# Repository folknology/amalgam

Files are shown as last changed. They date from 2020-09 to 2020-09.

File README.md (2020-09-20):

# Amalgam
Amalgam an OpenSource hardware fusion of FPGA and Cortex M7 Microcontroller in a [BlackEdge](https://github.com/folknology/BlackEdge) compatible layout, a project of the myStorm communtiy.

Current status is hardware design, you can see the developments we are making on my regular streams :
*  [Live Stream, 8pm BST](https://www.twitch.tv/folknology)
* [Historic streams](https://www.youtube.com/watch?v=79OoLG_Dxk0&list=PLXS9jyX9czzodpJNL-szsMfl0rOrZk4B7)
Or at the join us at the [myStorm community forum](https://forum.mystorm.uk)

We will be using an Alloy fusion framework on top of [nMigen](https://github.com/m-labs/nmigen) and [Circuit Python](https://github.com/adafruit/circuitpython) alonmg with verilog using [Yosys](https://github.com/YosysHQ/yosys)

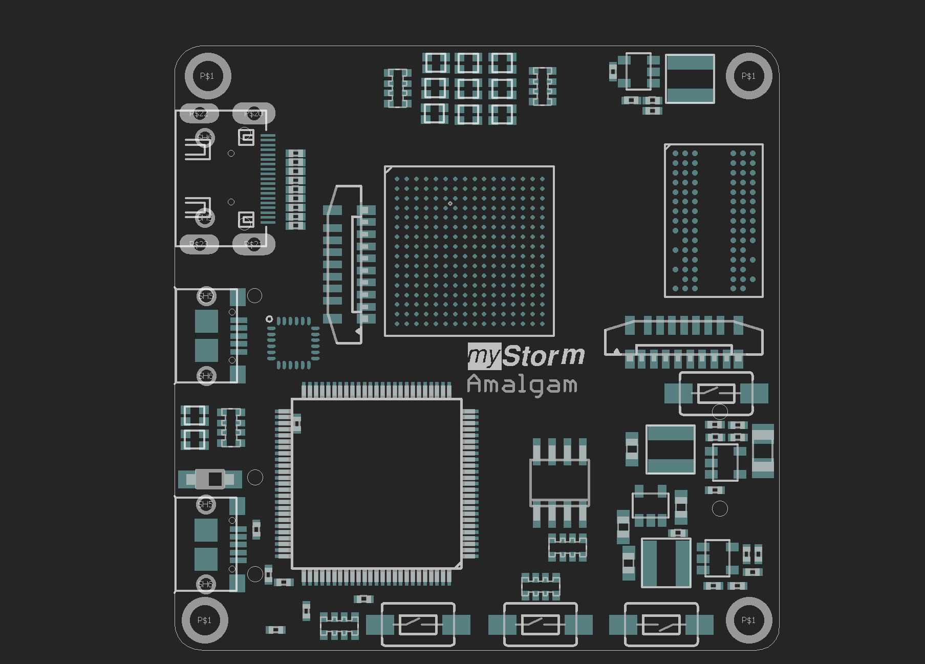
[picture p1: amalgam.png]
Amalgam


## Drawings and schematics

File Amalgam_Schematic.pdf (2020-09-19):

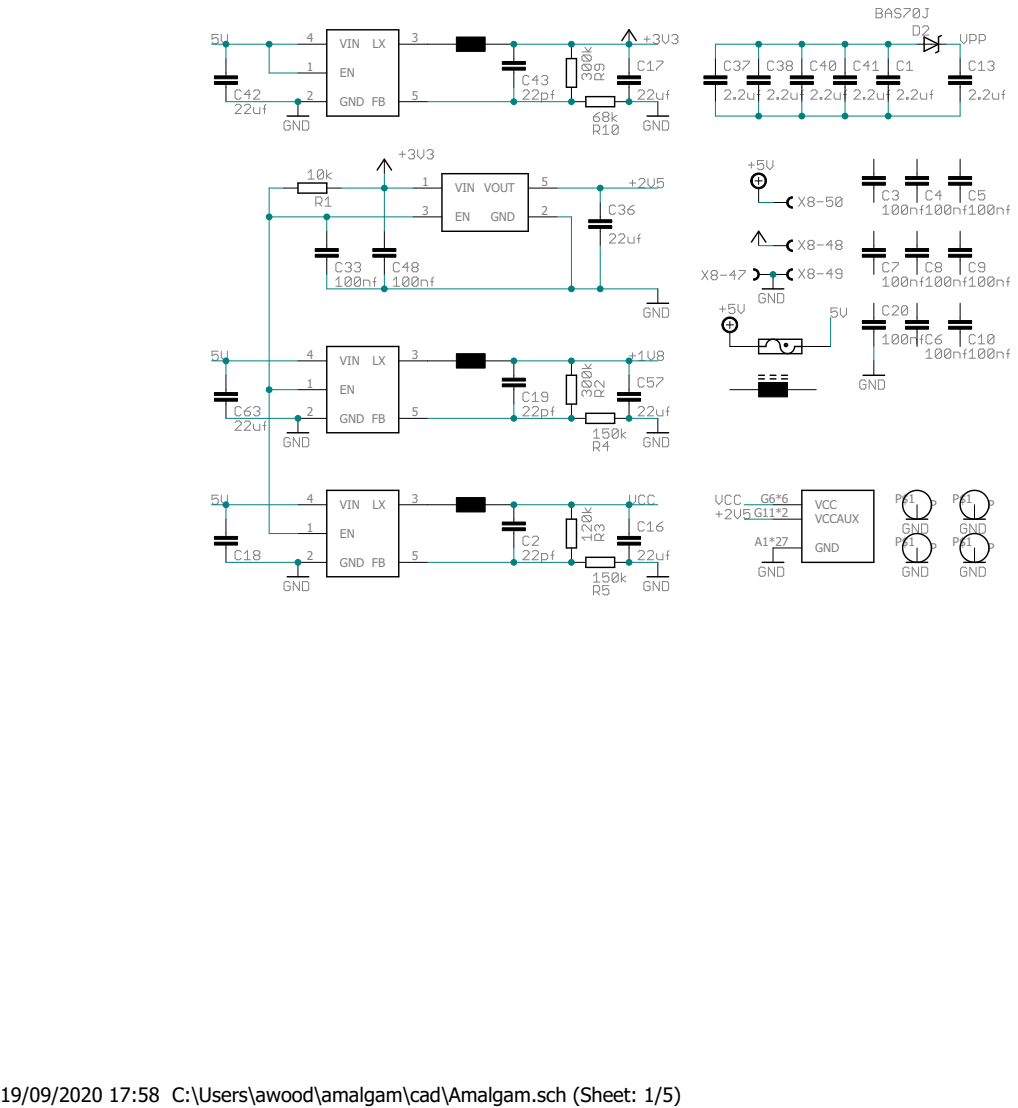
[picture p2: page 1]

19/09/2020 17:58 C:\Users\awood\amalgam\cad\Amalgam.sch (Sheet: 1/5)

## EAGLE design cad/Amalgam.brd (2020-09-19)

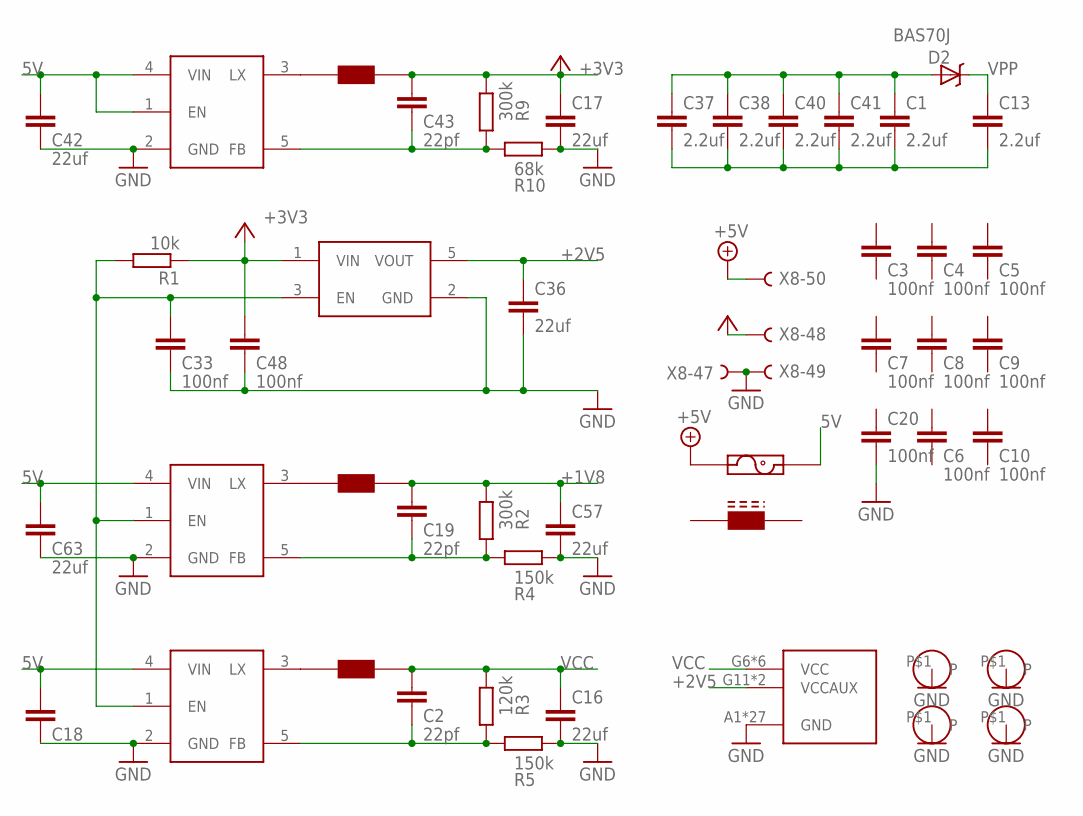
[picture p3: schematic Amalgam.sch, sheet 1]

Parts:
C1, C13, C37, C38, C40, C41: 2.2uf; C0603
C2, C19, C43: 22pf; C0402
C3, C4, C5, C6, C7, C8, C9, C10, C20, C33, C48: 100nf; C0402
C16, C17, C36, C57: 22uf; C0603
C18, C42, C63: 22uf; C0402
D2: BAS70J; SOD-323
IC7: NCP114; TSOP-5/SOT23-5
R1: 10k; R0402
R2, R9: 300k; R0402
R3: 120k; R0402
R4, R5: 150k; R0402
R10: 68k; R0402
U$1: PTC-1206; 1206
U$7, U$15, U$16, U$17: HOLE-2.5MM; 2.5MM-HOLE
U$12, U$13, U$20: AP3429/A; TSOP-5/SOT23-5
U$14: LFE5-XX256CABGA256; CABGA256
U$18, U$19, U$23: NRS4018; NRC4018
U$21: FERRITE_BEAD1206; 1206
X8: 1296-T50; 1296-50

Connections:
5V: C18.2, C42.2, C63.2, U$1.2, U$12.4 (VIN), U$13.4 (VIN), U$20.1 (EN), U$20.4 (VIN); also elsewhere on the board
+1V8: C19.2, C57.1, R2.2, U$19.P$2; also elsewhere on the board
+2V5: C36.1, IC7.5 (VOUT), U$14.G11 (VCCAUX), U$14.L7 (VCCAUX)
+3V3: C17.1, C43.2, C48.2, IC7.1 (VIN), R1.1, R9.2, U$23.P$2, X8.48; also elsewhere on the board
+5V: U$1.1, X8.50; also elsewhere on the board
GND: C16.2, C17.2, C18.1, C20.2, C33.1, C36.2, C42.1, C48.1, C57.2, C63.1, IC7.2 (GND), R4.2, R5.2, R10.2, U$7.P$1, U$12.2 (GND), U$13.2 (GND), U$14.A1 (GND), U$14.A16 (GND), U$14.D2 (GND), U$14.D15 (GND), U$14.F8 (GND), U$14.F9 (GND), U$14.G8 (GND), U$14.G10 (GND), U$14.H1 (GND), U$14.H8 (GND), U$14.H9 (GND), U$14.H10 (GND), U$14.H16 (GND), U$14.J8 (GND), U$14.J9 (GND), U$14.J10 (GND), U$14.K6 (GND), U$14.K7 (GND), U$14.K8 (GND), U$14.K9 (GND), U$14.K10 (GND), U$14.N2 (GND), U$14.N15 (GND), U$14.T1 (GND), U$14.T5 (GND), U$14.T12 (GND), U$14.T16 (GND), U$15.P$1, U$16.P$1, U$17.P$1, U$20.2 (GND), X8.47, X8.49; also elsewhere on the board
unnamed: C33.2, IC7.3 (EN), R1.2, U$12.1 (EN), U$13.1 (EN)
unnamed: C19.1, R2.1, R4.1, U$12.5 (FB)
unnamed: U$13.3 (LX), U$18.P$1
unnamed: U$12.3 (LX), U$19.P$1
unnamed: C2.1, R3.1, R5.1, U$13.5 (FB)
unnamed: C43.1, R9.1, R10.1, U$20.5 (FB)
unnamed: U$20.3 (LX), U$23.P$1
unnamed: C1.2, C13.2, C37.2, C38.2, C40.2, C41.2
unnamed: C1.1, C37.1, C38.1, C40.1, C41.1, D2.A
VCC: C2.2, C16.1, R3.2, U$14.G6 (VCC), U$14.G7 (VCC), U$14.G9 (VCC), U$14.L8 (VCC), U$14.L9 (VCC), U$14.L10 (VCC), U$18.P$2
VPP: C13.1, D2.C

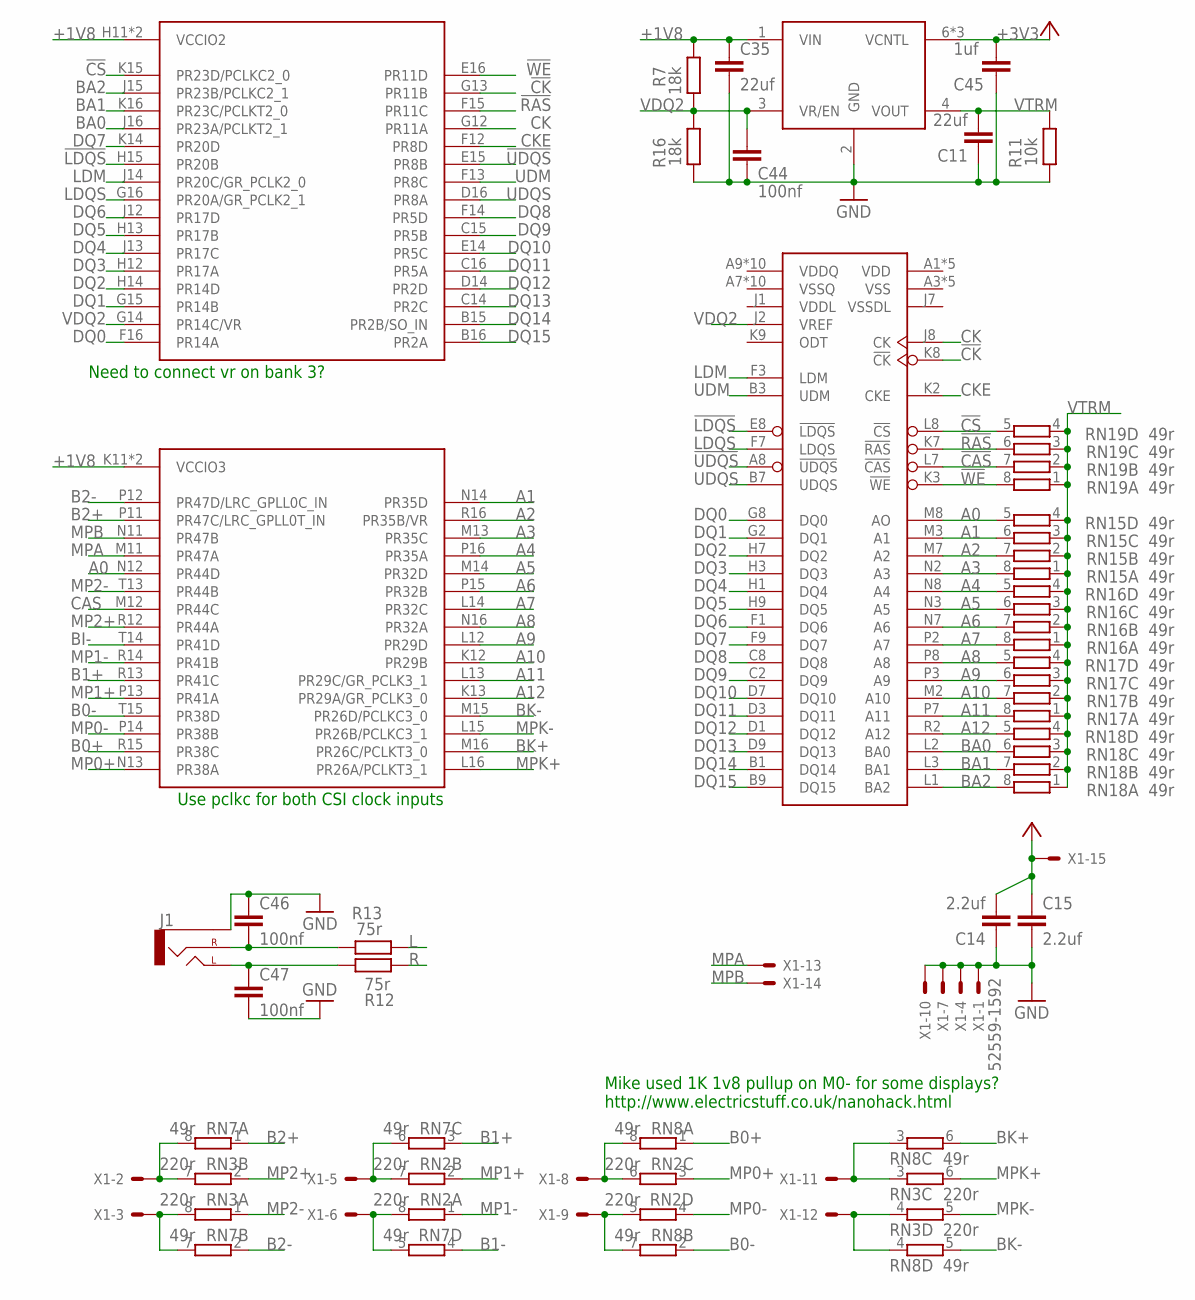
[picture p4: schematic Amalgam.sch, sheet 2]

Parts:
C11, C35: 22uf; C0603
C14, C15: 2.2uf; C0603
C44: 100nf; C0402
C45: 1uf; C0402
C46, C47: 100nf; C0603
J1: AUDIO_JACK_2.5MM_2.5MM_SMD; STEREOJACK2.5MM
R7, R16: 18k; R0402
R11: 10k; R0402
R12, R13: 75r; R0402
RN2, RN3: 220r; EXB38V
RN7, RN8, RN15, RN16, RN17, RN18, RN19: 49r; EXB38V
U$4: DDR2; WBGA-84
U$14: LFE5-XX256CABGA256; CABGA256
U$22: AP2303; SOIC-8-NARROW
X1: 52559-1592

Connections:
!CAS: RN19.7 (2), U$4.L7 (!CAS)
!CK: U$4.K8 (!CK), U$14.G13 (PR11B)
!CS: RN19.5 (2), U$4.L8 (!CS), U$14.K15 (PR23D/PCLKC2_0)
!LDQS: U$4.E8 (!LDQS), U$14.H15 (PR20B)
!RAS: RN19.6 (2), U$4.K7 (!RAS), U$14.F15 (PR11C)
!UDQS: U$4.A8 (!UDQS), U$14.E15 (PR8B)
!WE: RN19.8 (2), U$4.K3 (!WE), U$14.E16 (PR11D)
+1V8: C35.1, R7.1, U$14.H11 (VCCIO2), U$14.J11 (VCCIO2), U$14.K11 (VCCIO3), U$14.L11 (VCCIO3), U$22.1 (VIN); also elsewhere on the board
+3V3: C14.2, C15.1, C45.2, U$22.6 (VCNTL), U$22.7 (VCNTL), U$22.8 (VCNTL), X1.15; also elsewhere on the board
A0: RN15.5 (2), U$4.M8 (AO), U$14.N12 (PR44D)
A1: RN15.6 (2), U$4.M3 (A1), U$14.N14 (PR35D)
A2: RN15.7 (2), U$4.M7 (A2), U$14.R16 (PR35B/VR)
A3: RN15.8 (2), U$4.N2 (A3), U$14.M13 (PR35C)
A4: RN16.5 (2), U$4.N8 (A4), U$14.P16 (PR35A)
A5: RN16.6 (2), U$4.N3 (A5), U$14.M14 (PR32D)
A6: RN16.7 (2), U$4.N7 (A6), U$14.P15 (PR32B)
A7: RN16.8 (2), U$4.P2 (A7), U$14.L14 (PR32C)
A8: RN17.5 (2), U$4.P8 (A8), U$14.N16 (PR32A)
A9: RN17.6 (2), U$4.P3 (A9), U$14.L12 (PR29D)
A10: RN17.7 (2), U$4.M2 (A10), U$14.K12 (PR29B)
A11: RN17.8 (2), U$4.P7 (A11), U$14.L13 (PR29C/GR_PCLK3_1)
A12: RN18.5 (2), U$4.R2 (A12), U$14.K13 (PR29A/GR_PCLK3_0)
B0+: RN8.1, U$14.R15 (PR38C)
B0-: RN8.2 (1), U$14.T15 (PR38D)
B1+: RN7.3 (1), U$14.R13 (PR41C)
B1-: RN7.4 (1)
B2+: RN7.1, U$14.P11 (PR47C/LRC_GPLL0T_IN)
B2-: RN7.2 (1), U$14.P12 (PR47D/LRC_GPLL0C_IN)
BA0: RN18.6 (2), U$4.L2 (BA0), U$14.J16 (PR23A/PCLKT2_1)
BA1: RN18.7 (2), U$4.L3 (BA1), U$14.K16 (PR23C/PCLKT2_0)
BA2: RN18.8 (2), U$4.L1 (BA2), U$14.J15 (PR23B/PCLKC2_1)
BI-: U$14.T14 (PR41D)
BK+: RN8.6 (2), U$14.M16 (PR26C/PCLKT3_0)
BK-: RN8.5 (2), U$14.M15 (PR26D/PCLKC3_0)
CAS: U$14.M12 (PR44C)
CK: U$4.J8 (CK), U$14.G12 (PR11A)
CKE: U$4.K2 (CKE), U$14.F12 (PR8D)
DQ0: U$4.G8 (DQ0), U$14.F16 (PR14A)
DQ1: U$4.G2 (DQ1), U$14.G15 (PR14B)
DQ2: U$4.H7 (DQ2), U$14.H14 (PR14D)
DQ3: U$4.H3 (DQ3), U$14.H12 (PR17A)
DQ4: U$4.H1 (DQ4), U$14.J13 (PR17C)
DQ5: U$4.H9 (DQ5), U$14.H13 (PR17B)
DQ6: U$4.F1 (DQ6), U$14.J12 (PR17D)
DQ7: U$4.F9 (DQ7), U$14.K14 (PR20D)
DQ8: U$4.C8 (DQ8), U$14.F14 (PR5D)
DQ9: U$4.C2 (DQ9), U$14.C15 (PR5B)
DQ10: U$4.D7 (DQ10), U$14.E14 (PR5C)
DQ11: U$4.D3 (DQ11), U$14.C16 (PR5A)
DQ12: U$4.D1 (DQ12), U$14.D14 (PR2D)
DQ13: U$4.D9 (DQ13), U$14.C14 (PR2C)
DQ14: U$4.B1 (DQ14), U$14.B15 (PR2B/SO_IN)
DQ15: U$4.B9 (DQ15), U$14.B16 (PR2A)
GND: C11.1, C14.1, C15.2, C35.2, C44.1, C45.1, C46.1, C47.2, J1.5 (SLEEVE), R11.2, R16.2, U$22.2 (GND), X1.1, X1.4, X1.7, X1.10; also elsewhere on the board
L: R13.1; also elsewhere on the board
LDM: U$4.F3 (LDM), U$14.J14 (PR20C/GR_PCLK2_0)
LDQS: U$4.F7 (LDQS), U$14.G16 (PR20A/GR_PCLK2_1)
MP0+: RN2.3 (1), U$14.N13 (PR38A)
MP0-: RN2.4 (1), U$14.P14 (PR38B)
MP1+: RN2.2 (1), U$14.P13 (PR41A)
MP1-: RN2.1, U$14.R14 (PR41B)
MP2+: RN3.2 (1), U$14.R12 (PR44A)
MP2-: RN3.1, U$14.T13 (PR44B)
MPA: U$14.M11 (PR47A), X1.13
MPB: U$14.N11 (PR47B), X1.14
MPK+: RN3.6 (2), U$14.L16 (PR26A/PCLKT3_1)
MPK-: RN3.5 (2), U$14.L15 (PR26B/PCLKC3_1)
unnamed: RN3.3 (1), RN8.3 (1), X1.11
unnamed: RN3.4 (1), RN8.4 (1), X1.12
unnamed: RN2.6 (2), RN8.8 (2), X1.8
unnamed: RN2.5 (2), RN8.7 (2), X1.9
unnamed: RN2.7 (2), RN7.6 (2), X1.5
unnamed: RN2.8 (2), RN7.5 (2), X1.6
unnamed: RN3.8 (2), RN7.7 (2), X1.3
unnamed: RN3.7 (2), RN7.8 (2), X1.2
unnamed: C46.2, J1.4 (RIGHT), R13.2
unnamed: C47.1, J1.1 (LEFT), R12.1
R: R12.2; also elsewhere on the board
UDM: U$4.B3 (UDM), U$14.F13 (PR8C)
UDQS: U$4.B7 (UDQS), U$14.D16 (PR8A)
VDQ2: C44.2, R7.2, R16.1, U$4.J2 (VREF), U$14.G14 (PR14C/VR), U$22.3 (VR/EN)
VTRM: C11.2, R11.1, RN15.1, RN15.2 (1), RN15.3 (1), RN15.4 (1), RN16.1, RN16.2 (1), RN16.3 (1), RN16.4 (1), RN17.1, RN17.2 (1), RN17.3 (1), RN17.4 (1), RN18.1, RN18.2 (1), RN18.3 (1), RN18.4 (1), RN19.1, RN19.2 (1), RN19.3 (1), RN19.4 (1), U$22.4 (VOUT)

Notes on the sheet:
Need to connect vr on bank 3?
Use pclkc for both CSI clock inputs
Mike used 1K 1v8 pullup on M0- for some displays? http://www.electricstuff.co.uk/nanohack.html

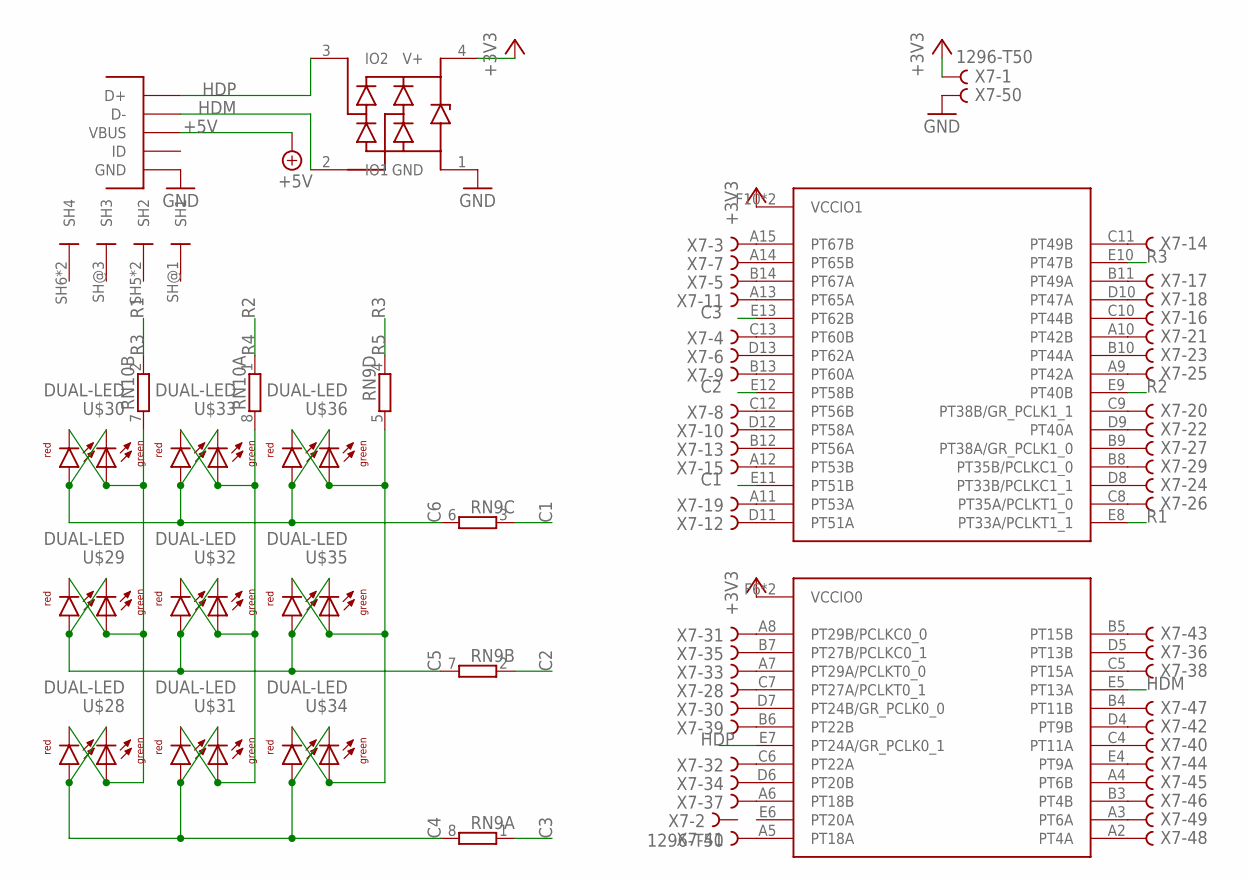
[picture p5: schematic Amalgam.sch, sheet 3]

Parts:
ESD1: PRTR5V0U2X; SOT143B
RN9, RN10: 4R-NEXB38V; EXB38V
U$11: FCI-MICROUSB-B-PEG; MICROUSB-B-PEG
U$14: LFE5-XX256CABGA256; CABGA256
U$28, U$29, U$30, U$31, U$32, U$33, U$34, U$35, U$36: DUAL-LED; DUAL-0603
X7: 1296-T50; 1296-50

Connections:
+3V3: ESD1.4 (V+), U$14.F6 (VCCIO0), U$14.F7 (VCCIO0), U$14.F10 (VCCIO1), U$14.F11 (VCCIO1), X7.1; also elsewhere on the board
+5V: U$11.P$1 (VBUS); also elsewhere on the board
C1: RN9.3 (1), U$14.E11 (PT51B)
C2: RN9.2 (1), U$14.E12 (PT58B)
C3: RN9.1, U$14.E13 (PT62B)
C4: RN9.8 (2), U$28.A1 (AR), U$28.C2 (CG), U$31.A1 (AR), U$31.C2 (CG), U$34.A1 (AR), U$34.C2 (CG)
C5: RN9.7 (2), U$29.A1 (AR), U$29.C2 (CG), U$32.A1 (AR), U$32.C2 (CG), U$35.A1 (AR), U$35.C2 (CG)
C6: RN9.6 (2), U$30.A1 (AR), U$30.C2 (CG), U$33.A1 (AR), U$33.C2 (CG), U$36.A1 (AR), U$36.C2 (CG)
GND: ESD1.1 (GND), U$11.P$5 (GND), X7.50; also elsewhere on the board
HDM: ESD1.2 (IO1), U$11.P$2 (D-), U$14.E5 (PT13A)
HDP: ESD1.3 (IO2), U$11.P$3 (D+), U$14.E7 (PT24A/GR_PCLK0_1)
unnamed: U$14.B3 (PT4B), X7.46
unnamed: U$14.A2 (PT4A), X7.48
unnamed: U$14.A15 (PT67B), X7.3
unnamed: U$14.B14 (PT67A), X7.5
unnamed: U$14.A14 (PT65B), X7.7
unnamed: U$14.B13 (PT60A), X7.9
unnamed: U$14.A13 (PT65A), X7.11
unnamed: U$14.B12 (PT56A), X7.13
unnamed: U$14.A12 (PT53B), X7.15
unnamed: U$14.B11 (PT49A), X7.17
unnamed: U$14.A11 (PT53A), X7.19
unnamed: U$14.C13 (PT60B), X7.4
unnamed: U$14.D13 (PT62A), X7.6
unnamed: U$14.C12 (PT56B), X7.8
unnamed: U$14.D12 (PT58A), X7.10
unnamed: U$14.A8 (PT29B/PCLKC0_0), X7.31
unnamed: U$14.A7 (PT29A/PCLKT0_0), X7.33
unnamed: U$14.B7 (PT27B/PCLKC0_1), X7.35
unnamed: U$14.A6 (PT18B), X7.37
unnamed: U$14.B6 (PT22B), X7.39
unnamed: U$14.A5 (PT18A), X7.41
unnamed: U$14.B5 (PT15B), X7.43
unnamed: U$14.C7 (PT27A/PCLKT0_1), X7.28
unnamed: U$14.D7 (PT24B/GR_PCLK0_0), X7.30
unnamed: U$14.C6 (PT22A), X7.32
unnamed: U$14.D6 (PT20B), X7.34
unnamed: U$14.D5 (PT13B), X7.36
unnamed: U$14.B4 (PT11B), X7.47
unnamed: U$14.A4 (PT6B), X7.45
unnamed: U$14.A3 (PT6A), X7.49
unnamed: U$14.D11 (PT51A), X7.12
unnamed: U$14.C11 (PT49B), X7.14
unnamed: U$14.C10 (PT44B), X7.16
unnamed: U$14.D10 (PT47A), X7.18
unnamed: U$14.A10 (PT42B), X7.21
unnamed: U$14.B10 (PT44A), X7.23
unnamed: U$14.A9 (PT42A), X7.25
unnamed: U$14.B9 (PT38A/GR_PCLK1_0), X7.27
unnamed: U$14.B8 (PT35B/PCLKC1_0), X7.29
unnamed: U$14.C9 (PT38B/GR_PCLK1_1), X7.20
unnamed: U$14.D9 (PT40A), X7.22
unnamed: U$14.D8 (PT33B/PCLKC1_1), X7.24
unnamed: U$14.C8 (PT35A/PCLKT1_0), X7.26
unnamed: U$14.C5 (PT15A), X7.38
unnamed: U$14.C4 (PT11A), X7.40
unnamed: U$14.D4 (PT9B), X7.42
unnamed: U$14.E4 (PT9A), X7.44
R1: RN10.2 (1), U$14.E8 (PT33A/PCLKT1_1)
R2: RN10.1, U$14.E9 (PT40B)
R3: RN9.4 (1), RN10.7 (2), U$14.E10 (PT47B), U$28.A2 (AG), U$28.C1 (CR), U$29.A2 (AG), U$29.C1 (CR), U$30.A2 (AG), U$30.C1 (CR)
R4: RN10.8 (2), U$31.A2 (AG), U$31.C1 (CR), U$32.A2 (AG), U$32.C1 (CR), U$33.A2 (AG), U$33.C1 (CR)
R5: RN9.5 (2), U$34.A2 (AG), U$34.C1 (CR), U$35.A2 (AG), U$35.C1 (CR), U$36.A2 (AG), U$36.C1 (CR)

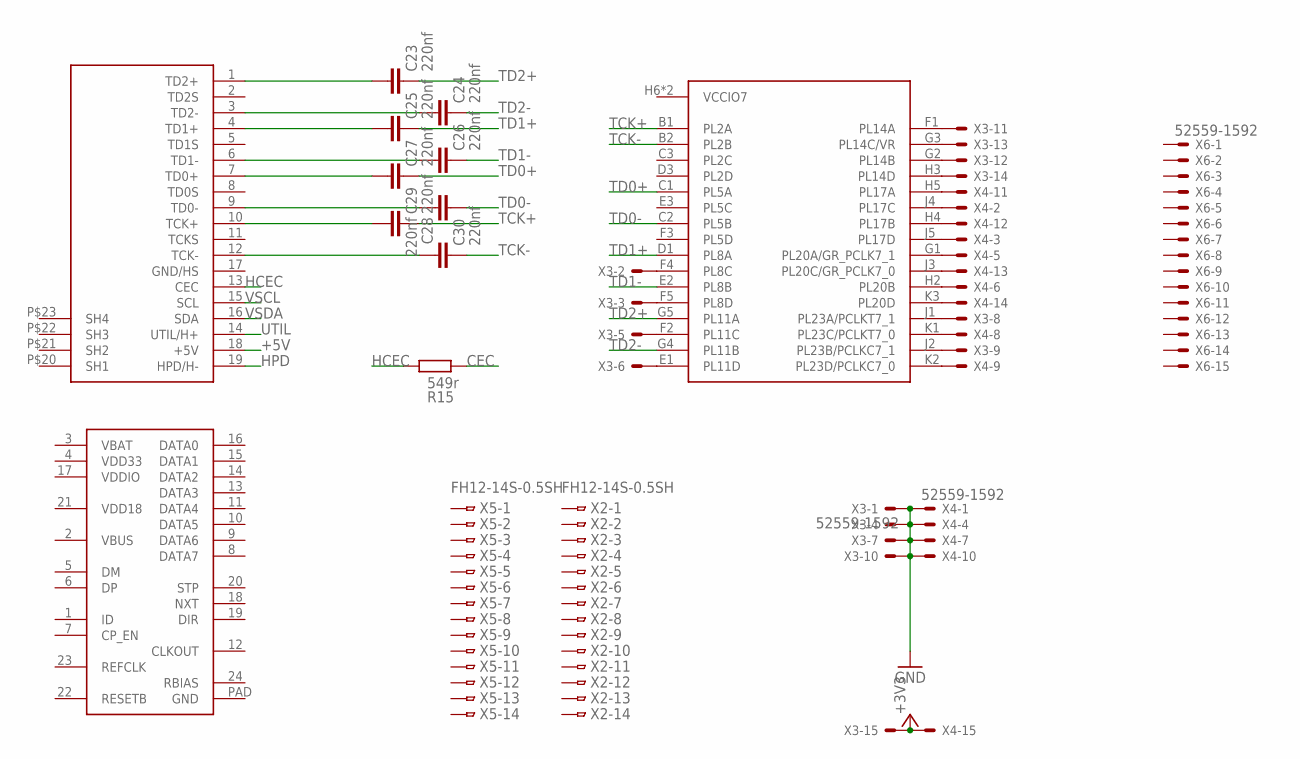
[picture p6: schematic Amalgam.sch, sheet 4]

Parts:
C23, C24, C25, C26, C27, C28, C29, C30: 220nf; C0402
R15: 549r; R0402
U$9: HD10-001_HDMIMINI-HDMI; MINI-HDMI
U$14: LFE5-XX256CABGA256; CABGA256
U$25: USB3318-QFN24; 24-QFN
X2, X5: FH12-14S-0.5SH
X3, X4, X6: 52559-1592

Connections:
+3V3: X3.15, X4.15; also elsewhere on the board
+5V: U$9.18 (+5V); also elsewhere on the board
CEC: R15.2; also elsewhere on the board
GND: U$25.PAD (GND), X3.1, X3.4, X3.7, X3.10, X4.1, X4.4, X4.7, X4.10; also elsewhere on the board
HCEC: R15.1, U$9.13 (CEC)
HPD: U$9.19 (HPD/H-); also elsewhere on the board
unnamed: U$14.K3 (PL20D), X4.14
unnamed: U$14.J3 (PL20C/GR_PCLK7_0), X4.13
unnamed: U$14.J1 (PL23A/PCLKT7_1), X3.8
unnamed: U$14.J2 (PL23B/PCLKC7_1), X3.9
unnamed: U$14.K1 (PL23C/PCLKT7_0), X4.8
unnamed: U$14.K2 (PL23D/PCLKC7_0), X4.9
unnamed: U$14.H2 (PL20B), X4.6
unnamed: U$14.G1 (PL20A/GR_PCLK7_1), X4.5
unnamed: U$14.J5 (PL17D), X4.3
unnamed: U$14.J4 (PL17C), X4.2
unnamed: U$14.H4 (PL17B), X4.12
unnamed: U$14.H5 (PL17A), X4.11
unnamed: U$14.H3 (PL14D), X3.14
unnamed: U$14.G3 (PL14C/VR), X3.13
unnamed: U$14.G2 (PL14B), X3.12
unnamed: U$14.F1 (PL14A), X3.11
unnamed: U$14.E1 (PL11D), X3.6
unnamed: U$14.F2 (PL11C), X3.5
unnamed: U$14.F5 (PL8D), X3.3
unnamed: C23.2, U$9.1 (TD2+)
unnamed: C24.2, U$9.3 (TD2-)
unnamed: C25.2, U$9.4 (TD1+)
unnamed: C26.2, U$9.6 (TD1-)
unnamed: C27.2, U$9.7 (TD0+)
unnamed: C28.1, U$9.9 (TD0-)
unnamed: C29.2, U$9.10 (TCK+)
unnamed: U$14.F4 (PL8C), X3.2
unnamed: C30.2, U$9.12 (TCK-)
TCK+: C29.1, U$14.B1 (PL2A)
TCK-: C30.1, U$14.B2 (PL2B)
TD0+: C27.1, U$14.C1 (PL5A)
TD0-: C28.2, U$14.C2 (PL5B)
TD1+: C25.1, U$14.D1 (PL8A)
TD1-: C26.1, U$14.E2 (PL8B)
TD2+: C23.1, U$14.G5 (PL11A)
TD2-: C24.1, U$14.G4 (PL11B)
UTIL: U$9.14 (UTIL/H+)
VBAT: U$25.3 (VBAT)
VDD18: U$25.21 (VDD18)
VDD33: U$25.4 (VDD33)
VDDIO: U$25.17 (VDDIO)
VSCL: U$9.15 (SCL); also elsewhere on the board
VSDA: U$9.16 (SDA); also elsewhere on the board

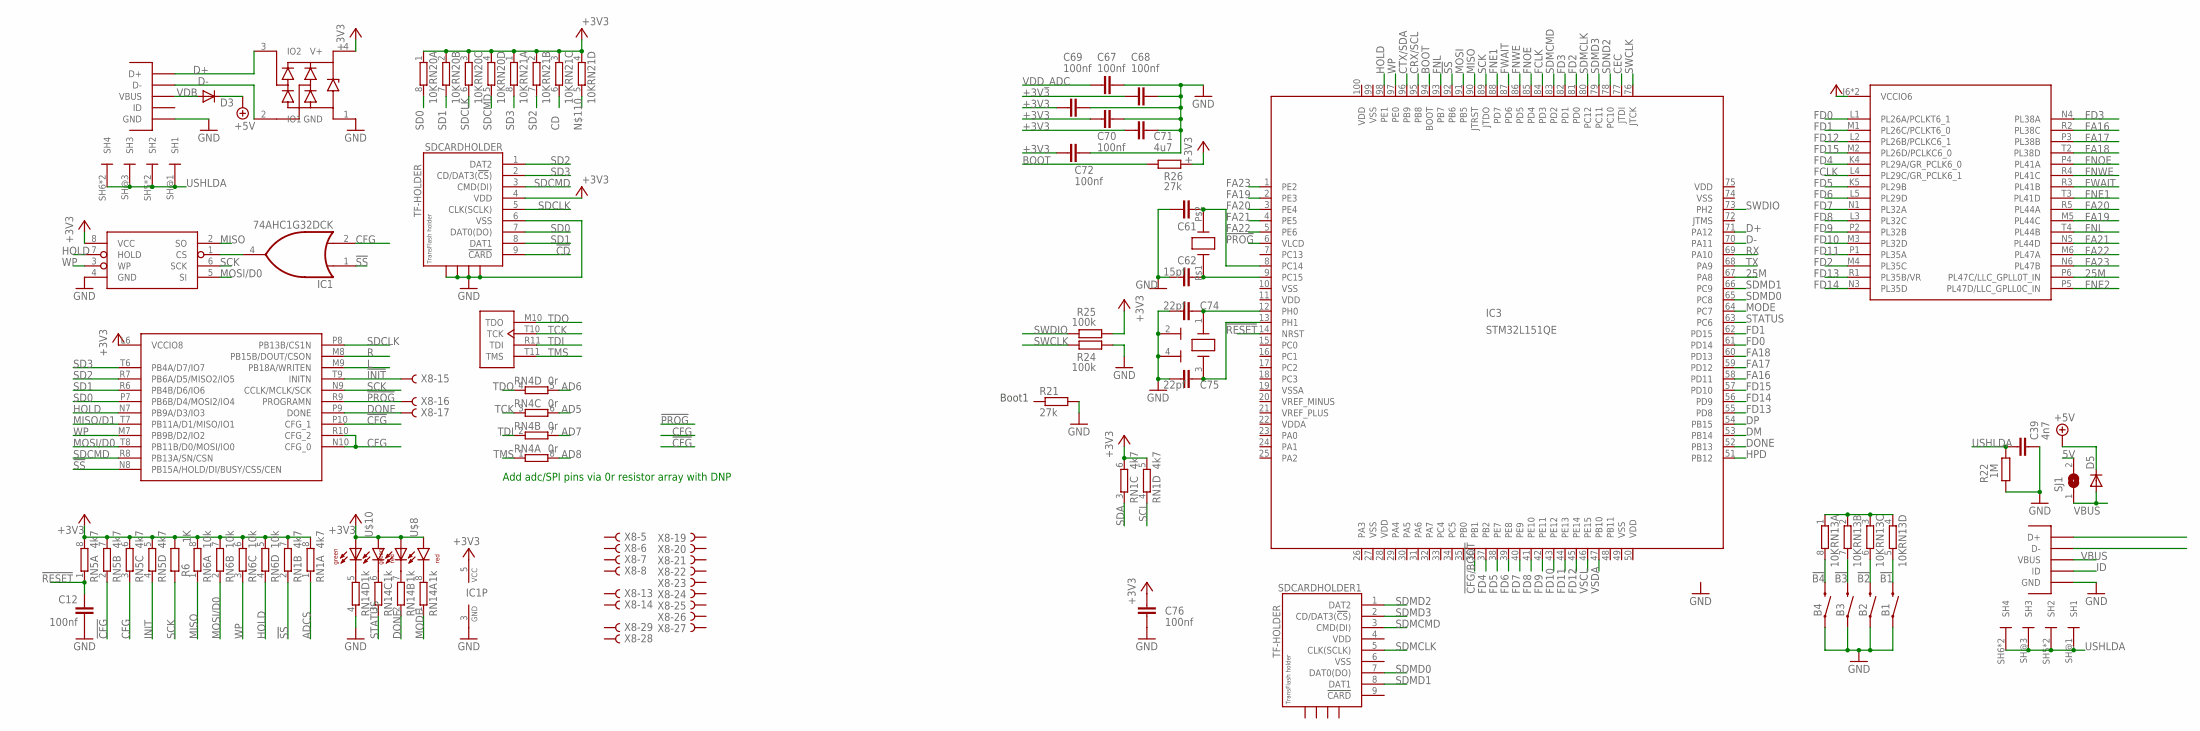
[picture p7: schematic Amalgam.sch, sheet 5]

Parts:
B1, B2, B3, B4: RS SWITCH; TACTILE-SWITCH-1101NE
C12, C67, C68, C69, C70, C72, C76: 100nf; C0402
C39: 4n7; C0402
C61, C62: 15pf; C0402
C71: 4u7; C0402
C74, C75: 22pf; C0402
D3, D5: DIODE-SOD123; SOD123
ESD2: PRTR5V0U2X; SOT143B
IC1: 74AHC1G32DCK; SC70-5
IC3: STM32L151QE; LQFP100_14X14
R6: 1K; R0402
R21, R26: 27k; R0402
R22: 1M; R0402
R24, R25: 100k; R0402
RN1, RN5: 4k7; EXB38V
RN4: 0r; EXB38V
RN6: 10k; EXB38V
RN13, RN20, RN21: 10K; EXB38V
RN14: 1k; EXB38V
SDCARDHOLDER, SDCARDHOLDER1: TF-HOLDER; TF-PULL
SJ1: SJ
U$2: AT25SDF041A; SOIC-8-NARROW
U$3: FC-135; FC135
U$5, U$6: FCI-MICROUSB-B-PEG; MICROUSB-B-PEG
U$8, U$10: DUAL-LED; DUAL-0603
U$14: LFE5-XX256CABGA256; CABGA256
X8: 1296-T50; 1296-50
Y3: 12MZ; CRYSTAL-3.2X2.5

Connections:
5V: SJ1.2; also elsewhere on the board
25M: IC3.67 (PA8), U$14.P6 (PL47C/LLC_GPLL0T_IN)
!B1: B1.2, RN13.5 (2)
!B2: B2.2, RN13.6 (2)
!B3: B3.2, RN13.7 (2)
!B4: B4.2, RN13.8 (2)
!CD: SDCARDHOLDER.9 (!CARD)
!CFG: RN5.2 (1), U$14.P10 (CFG_1)
!CFG/BOOT: IC3.36 (PB1)
!INIT: U$14.T9 (INITN), X8.15
!PROG: IC3.6 (VLCD), U$14.R9 (PROGRAMN), X8.16
!RESET: C12.1, IC3.14 (NRST), RN5.1
!SS: IC1.1 (I0), IC3.92 (PB6), RN1.2 (1), U$14.N8 (PB15A/HOLD/DI/BUSY/CSS/CEN)
+3V3: C68.2, C69.2, C70.2, C71.2, C72.2, C76.1, ESD2.4 (V+), IC1.5 (VCC), R6.2, R25.1, R26.2, RN1.5 (2), RN1.6 (2), RN1.7 (2), RN1.8 (2), RN5.5 (2), RN5.6 (2), RN5.7 (2), RN5.8 (2), RN6.5 (2), RN6.6 (2), RN6.7 (2), RN6.8 (2), RN20.1, RN20.2 (1), RN20.3 (1), RN20.4 (1), RN21.1, RN21.2 (1), RN21.3 (1), RN21.4 (1), SDCARDHOLDER.4 (VDD), U$2.8 (VCC), U$8.A1 (AR), U$8.A2 (AG), U$10.A1 (AR), U$10.A2 (AG), U$14.J6 (VCCIO6), U$14.J7 (VCCIO6), U$14.L6 (VCCIO8); also elsewhere on the board
+5V: D3.C, D5.C; also elsewhere on the board
AD5: RN4.6 (2)
AD6: RN4.5 (2)
AD7: RN4.7 (2)
AD8: RN4.8 (2)
ADCS: RN1.1
BOOT: IC3.94 (BOOT), R26.1
CD: RN21.6 (2)
CEC: IC3.77 (JTDI); also elsewhere on the board
CFG: IC1.2 (I1), RN5.3 (1), U$14.N10 (CFG_0), U$14.R10 (CFG_2)
CRX/SCL: IC3.95 (PB8)
CTX/SDA: IC3.96 (PB9)
D+: ESD2.3 (IO2), IC3.71 (PA12), U$5.P$3 (D+)
D-: ESD2.2 (IO1), IC3.70 (PA11), U$5.P$2 (D-)
DM: IC3.53 (PB14)
DONE: IC3.52 (PB13), RN14.2 (1), U$14.P9 (DONE), X8.17
DP: IC3.54 (PB15)
FA16: IC3.58 (PD11), U$14.R2 (PL38C)
FA17: IC3.59 (PD12), U$14.P3 (PL38B)
FA18: IC3.60 (PD13), U$14.T2 (PL38D)
FA19: IC3.2 (PE3), U$14.M5 (PL44C)
FA20: IC3.3 (PE4), U$14.R5 (PL44A)
FA21: IC3.4 (PE5), U$14.N5 (PL44D)
FA22: IC3.5 (PE6), U$14.M6 (PL47A)
FA23: IC3.1 (PE2), U$14.N6 (PL47B)
FCLK: IC3.84 (PD3), U$14.L4 (PL29C/GR_PCLK6_1)
FD0: IC3.61 (PD14), U$14.L1 (PL26A/PCLKT6_1)
FD1: IC3.62 (PD15), U$14.M1 (PL26C/PCLKT6_0)
FD2: IC3.81 (PD0), U$14.M4 (PL35C)
FD3: IC3.82 (PD1), U$14.N4 (PL38A)
FD4: IC3.37 (PB2), U$14.K4 (PL29A/GR_PCLK6_0)
FD5: IC3.38 (PE7), U$14.K5 (PL29B)
FD6: IC3.39 (PE8), U$14.L5 (PL29D)
FD7: IC3.40 (PE9), U$14.N1 (PL32A)
FD8: IC3.41 (PE10), U$14.L3 (PL32C)
FD9: IC3.42 (PE11), U$14.P2 (PL32B)
FD10: IC3.43 (PE12), U$14.M3 (PL32D)
FD11: IC3.44 (PE13), U$14.P1 (PL35A)
FD12: IC3.45 (PE14), U$14.L2 (PL26B/PCLKC6_1)
FD13: IC3.55 (PD8), U$14.R1 (PL35B/VR)
FD14: IC3.56 (PD9), U$14.N3 (PL35D)
FD15: IC3.57 (PD10), U$14.M2 (PL26D/PCLKC6_0)
FNE1: IC3.88 (PD7), U$14.T3 (PL41D)
FNE2: U$14.P5 (PL47D/LLC_GPLL0C_IN)
FNL: IC3.93 (PB7), U$14.T4 (PL44B)
FNOE: IC3.85 (PD4), U$14.P4 (PL41A)
FNWE: IC3.86 (PD5), U$14.R4 (PL41C)
FWAIT: IC3.87 (PD6), U$14.R3 (PL41B)
GND: B1.1, B2.1, B3.1, B4.1, C12.2, C39.1, C61.1, C62.1, C67.1, C68.1, C69.1, C70.1, C71.1, C72.1, C74.1, C75.1, C76.2, ESD2.1 (GND), IC1.3 (GND), R21.2, R22.2, R24.1, RN14.4 (1), SDCARDHOLDER.6 (VSS), SDCARDHOLDER.S1, SDCARDHOLDER.S2, SDCARDHOLDER.S3, SDCARDHOLDER.S4, U$2.4 (GND), U$5.P$5 (GND), U$6.P$5 (GND), Y3.2 (GND), Y3.4 (GND); also elsewhere on the board
HOLD: IC3.98 (PE1), RN6.4 (1), U$2.7 (HOLD), U$14.N7 (PB9A/D3/IO3)
HPD: IC3.51 (PB12); also elsewhere on the board
ID: U$6.P$4 (ID)
INIT: RN5.4 (1)
L: U$14.M9 (PB18A/WRITEN); also elsewhere on the board
MISO: IC3.90 (JTRST), RN6.1, U$2.2 (SO)
MISO/D1: U$14.T7 (PB11A/D1/MISO/IO1)
MODE: IC3.64 (PC7), RN14.1
MOSI: IC3.91 (PB5)
MOSI/D0: RN6.2 (1), U$2.5 (SI), U$14.T8 (PB11B/D0/MOSI/IO0)
unnamed: C62.2, IC3.9 (PC15), U$3.P$1 (X1)
unnamed: IC1.4 (O), U$2.1 (CS)
unnamed: RN13.1, RN13.2 (1), RN13.3 (1), RN13.4 (1)
unnamed: C61.2, IC3.8 (PC14), U$3.P$2 (X2)
unnamed: RN14.5 (2), U$10.C2 (CG)
unnamed: RN14.6 (2), U$10.C1 (CR)
unnamed: RN14.7 (2), U$8.C2 (CG)
unnamed: RN14.8 (2), U$8.C1 (CR)
unnamed: C75.2, IC3.13 (PH1), Y3.3 (X2)
unnamed: C74.2, IC3.12 (PH0), Y3.1 (X1)
R: U$14.M8 (PB15B/DOUT/CSON); also elsewhere on the board
RX: IC3.69 (PA10)
SCK: IC3.89 (JTDO), R6.1, U$2.6 (SCK), U$14.N9 (CCLK/MCLK/SCK)
SCL: RN1.4 (1)
SD0: RN20.8 (2), SDCARDHOLDER.7 (DAT0(DO)), U$14.P7 (PB6B/D4/MOSI2/IO4)
SD1: RN20.7 (2), SDCARDHOLDER.8 (DAT1), U$14.R6 (PB4B/D6/IO6)
SD2: RN21.7 (2), SDCARDHOLDER.1 (DAT2), U$14.R7 (PB6A/D5/MISO2/IO5)
SD3: RN21.8 (2), SDCARDHOLDER.2 (CD/DAT3(!CS!)), U$14.T6 (PB4A/D7/IO7)
SDA: RN1.3 (1)
SDCLK: RN20.6 (2), SDCARDHOLDER.5 (CLK(SCLK)), U$14.P8 (PB13B/CS1N)
SDCMD: RN20.5 (2), SDCARDHOLDER.3 (CMD(DI)), U$14.R8 (PB13A/SN/CSN)
SDMCLK: IC3.80 (PC12), SDCARDHOLDER1.5 (CLK(SCLK))
SDMCMD: IC3.83 (PD2), SDCARDHOLDER1.3 (CMD(DI))
SDMD0: IC3.65 (PC8), SDCARDHOLDER1.7 (DAT0(DO))
SDMD1: IC3.66 (PC9), SDCARDHOLDER1.8 (DAT1)
SDMD2: SDCARDHOLDER1.1 (DAT2)
SDMD3: IC3.79 (PC11), SDCARDHOLDER1.2 (CD/DAT3(!CS!))
SDND2: IC3.78 (PC10)
STATUS: IC3.63 (PC6), RN14.3 (1)
SWCLK: IC3.76 (JTCK), R24.2
SWDIO: IC3.73 (PH2), R25.2
TCK: RN4.3 (1), U$14.T10 (TCK)
TDI: RN4.2 (1), U$14.R11 (TDI)
TDO: RN4.4 (1), U$14.M10 (TDO)
TMS: RN4.1, U$14.T11 (TMS)
TX: IC3.68 (PA9)
USHLDA: C39.2, R22.1, U$5.SH5 (SH2), U$5.SH6 (SH4), U$5.SH@1 (SH1), U$5.SH@2 (SH2), U$5.SH@3 (SH3), U$5.SH@4 (SH4), U$6.SH5 (SH2), U$6.SH6 (SH4), U$6.SH@1 (SH1), U$6.SH@2 (SH2), U$6.SH@3 (SH3), U$6.SH@4 (SH4)
VBUS: D5.A, SJ1.1, U$6.P$1 (VBUS)
VDB: D3.A, U$5.P$1 (VBUS)
VDD: IC3.11 (VDD), IC3.28 (VDD), IC3.50 (VDD), IC3.75 (VDD), IC3.100 (VDD), SDCARDHOLDER1.4 (VDD)
VDDA: IC3.22 (VDDA)
VDD_ADC: C67.2
VSCL: IC3.46 (PE15); also elsewhere on the board
VSDA: IC3.47 (PB10); also elsewhere on the board
VSS: IC3.10 (VSS), IC3.27 (VSS), IC3.49 (VSS), IC3.74 (VSS), IC3.99 (VSS), SDCARDHOLDER1.6 (VSS)
VSSA: IC3.19 (VSSA)
WP: IC3.97 (PE0), RN6.3 (1), U$2.3 (WP), U$14.M7 (PB9B/D2/IO2)

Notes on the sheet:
Add adc/SPI pins via 0r resistor array with DNP
Boot1

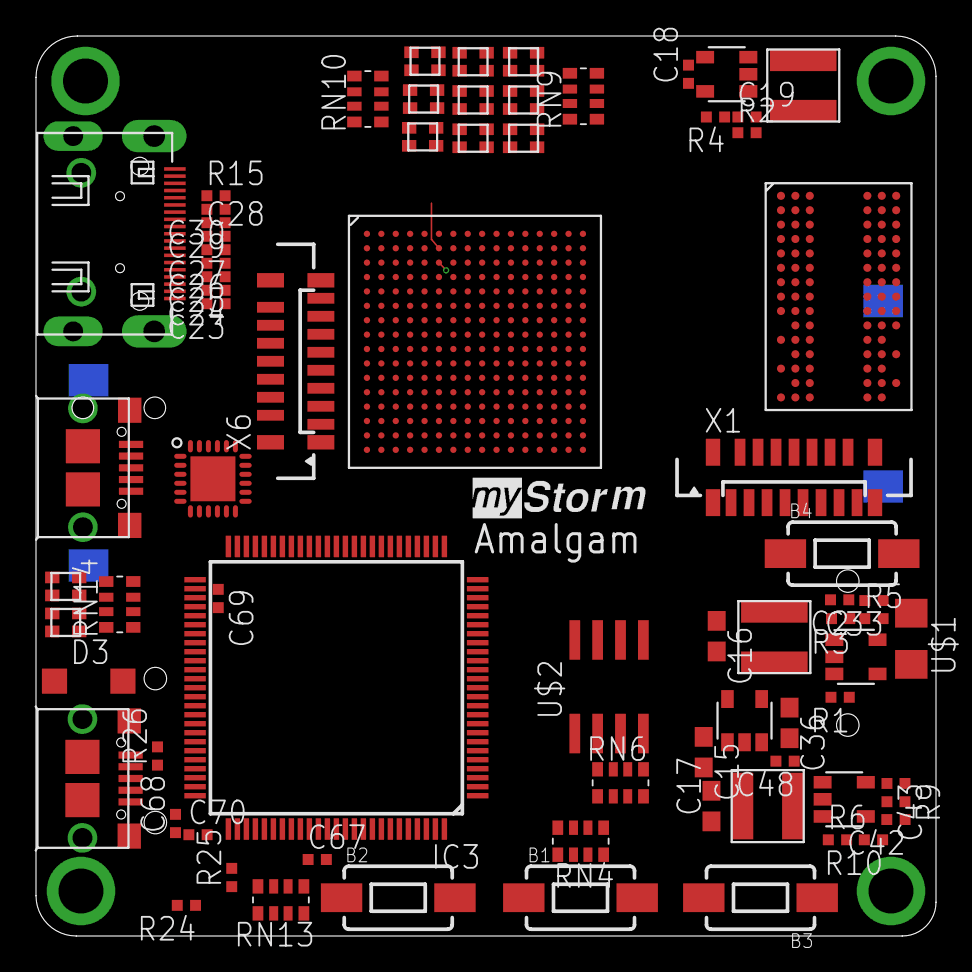
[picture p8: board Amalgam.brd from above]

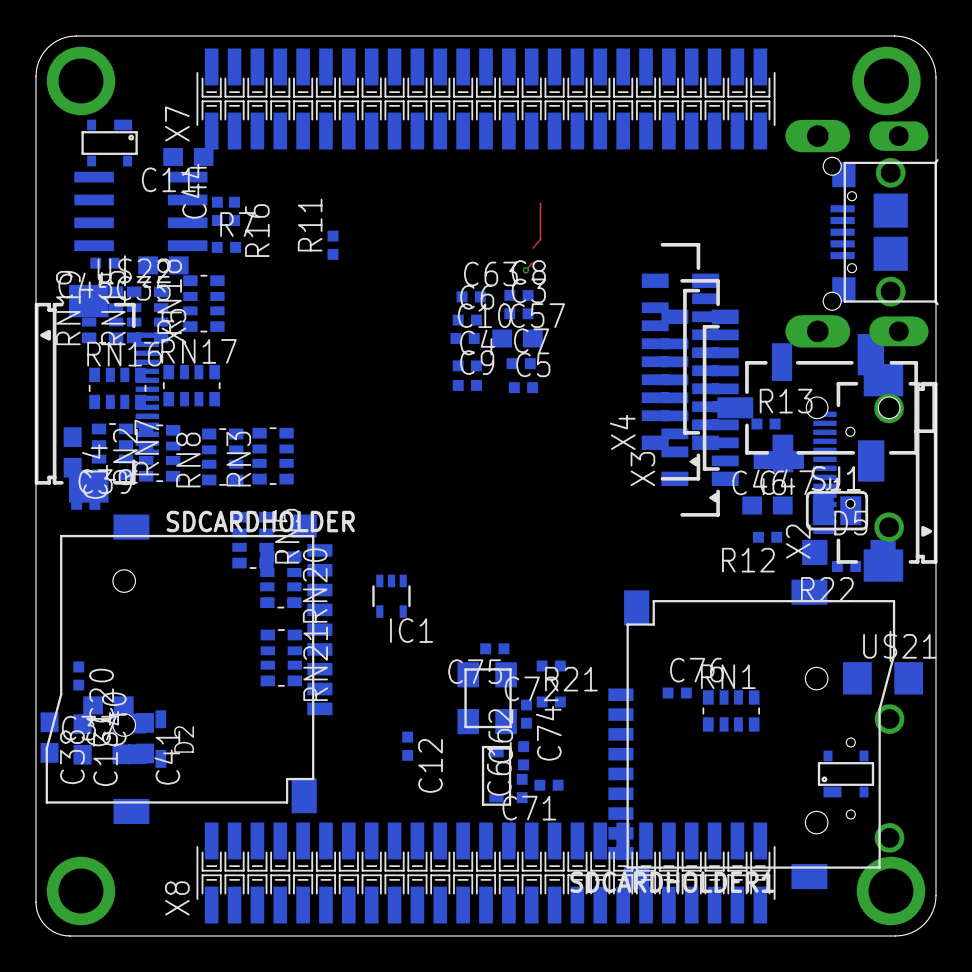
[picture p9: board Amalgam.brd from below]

Board: 4 copper layers, 50.0 x 50.0 mm, 152 parts (73 on the bottom side), 278 nets.

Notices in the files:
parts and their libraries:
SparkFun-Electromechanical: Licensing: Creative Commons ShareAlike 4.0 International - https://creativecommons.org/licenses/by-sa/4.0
